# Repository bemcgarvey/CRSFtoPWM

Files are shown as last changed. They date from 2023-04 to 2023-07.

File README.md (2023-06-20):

# CRSFtoPWM  
  
A board to provide up to 10 PWM servo outputs using an inexpensive serial ELRS receiver.  Tested with a BetaFPV Nano 2400 Rx  
Includes a pressure sensor for baro altitude and vertical speed telemetery. 
  
### Features:  
* 8 PWM servo outputs with adjustable update rate from 50Hz to 333Hz
* 2 PWM outputs fixed at 50Hz
* All pwm outputs can be mapped to any channel
* Optional SBus output of all channels
* Altitude and VSpeed telemetry over ELRS/CRSF
* Rx battery telemetry over ELRS
* Vbat from 2S to 6S or optionally from servo rail
* Extra UART port can be configured for gps telemetry, debugging, or Betaflight passthrough for ELRS rx firmware updates
* Extra I2C port for future expansion?
* Windows client software for configuration over a USB-Serial (FTDI etc.) connection.

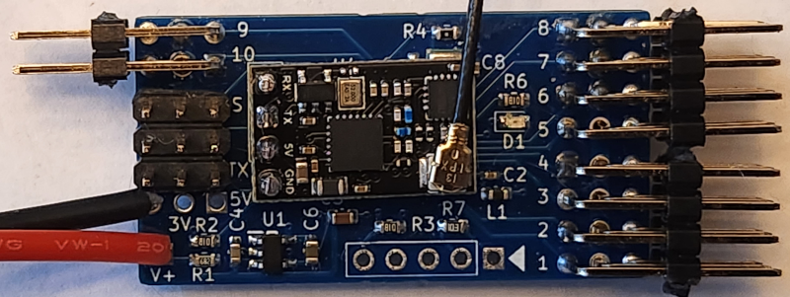
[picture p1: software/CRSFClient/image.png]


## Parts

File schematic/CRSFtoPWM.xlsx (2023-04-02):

Source: | C:\Projects\CRSFtoPWM\schematic\CRSFtoPWM.kicad_sch
Component Count: | 30
Ref | Qnty | Value | Footprint | Vendor
C1, C2, C8, C9, | 4 | 100nF | Capacitor_SMD:C_0402_1005Metric
C3, C6, | 2 | 10uF | Capacitor_SMD:C_0603_1608Metric
C4, | 1 | 1uF | Capacitor_SMD:C_0603_1608Metric
C5, | 1 | 1uF | Capacitor_SMD:C_0402_1005Metric
C7, | 1 | 2.2uF | Capacitor_SMD:C_0603_1608Metric
D1, | 1 | LED | LED_SMD:LED_0603_1608Metric
J1, | 1 | Bat+ | Connector_PinHeader_2.54mm:PinHeader_1x01_P2.54mm_Vertical
J2, | 1 | UART1/Rx | Connector_PinHeader_2.54mm:PinHeader_1x04_P2.54mm_Vertical
J3, | 1 | ICSP | Connector_PinHeader_2.54mm:PinHeader_1x05_P2.54mm_Vertical
J4, J5, J6, | 3 | TSW-104-08-G-T-RA | SamacSys_Parts:HDRRA12W64P254_3X4_1016X254X810P
J7, | 1 | TSW-102-08-L-T-RA | SamacSys_Parts:HDRRA6W64P254_3X2_508X254X810P
L1, | 1 | 470R | Inductor_SMD:L_0603_1608Metric
R1, | 1 | 6K8 | Resistor_SMD:R_0603_1608Metric
R2, R3, R6, | 3 | 1K | Resistor_SMD:R_0603_1608Metric
R4, R5, R7, | 3 | 10K | Resistor_SMD:R_0603_1608Metric
U1, | 1 | AP7375-50W5-7 | SamacSys_Parts:SOT95P285X140-5N
U2, | 1 | AP2210N-3.3TRG1 | SamacSys_Parts:SOT95P280X145-3N
U3, | 1 | ATSAMD21E18A-MU | SamacSys_Parts2:QFN50P500X500X100-33N-D
U4, | 1 | SN74AUP1G04DBVR | SamacSys_Parts2:SOT95P280X145-5N
U5, | 1 | MS563702BA03-50 | SamacSys_Parts2:MS5637_1

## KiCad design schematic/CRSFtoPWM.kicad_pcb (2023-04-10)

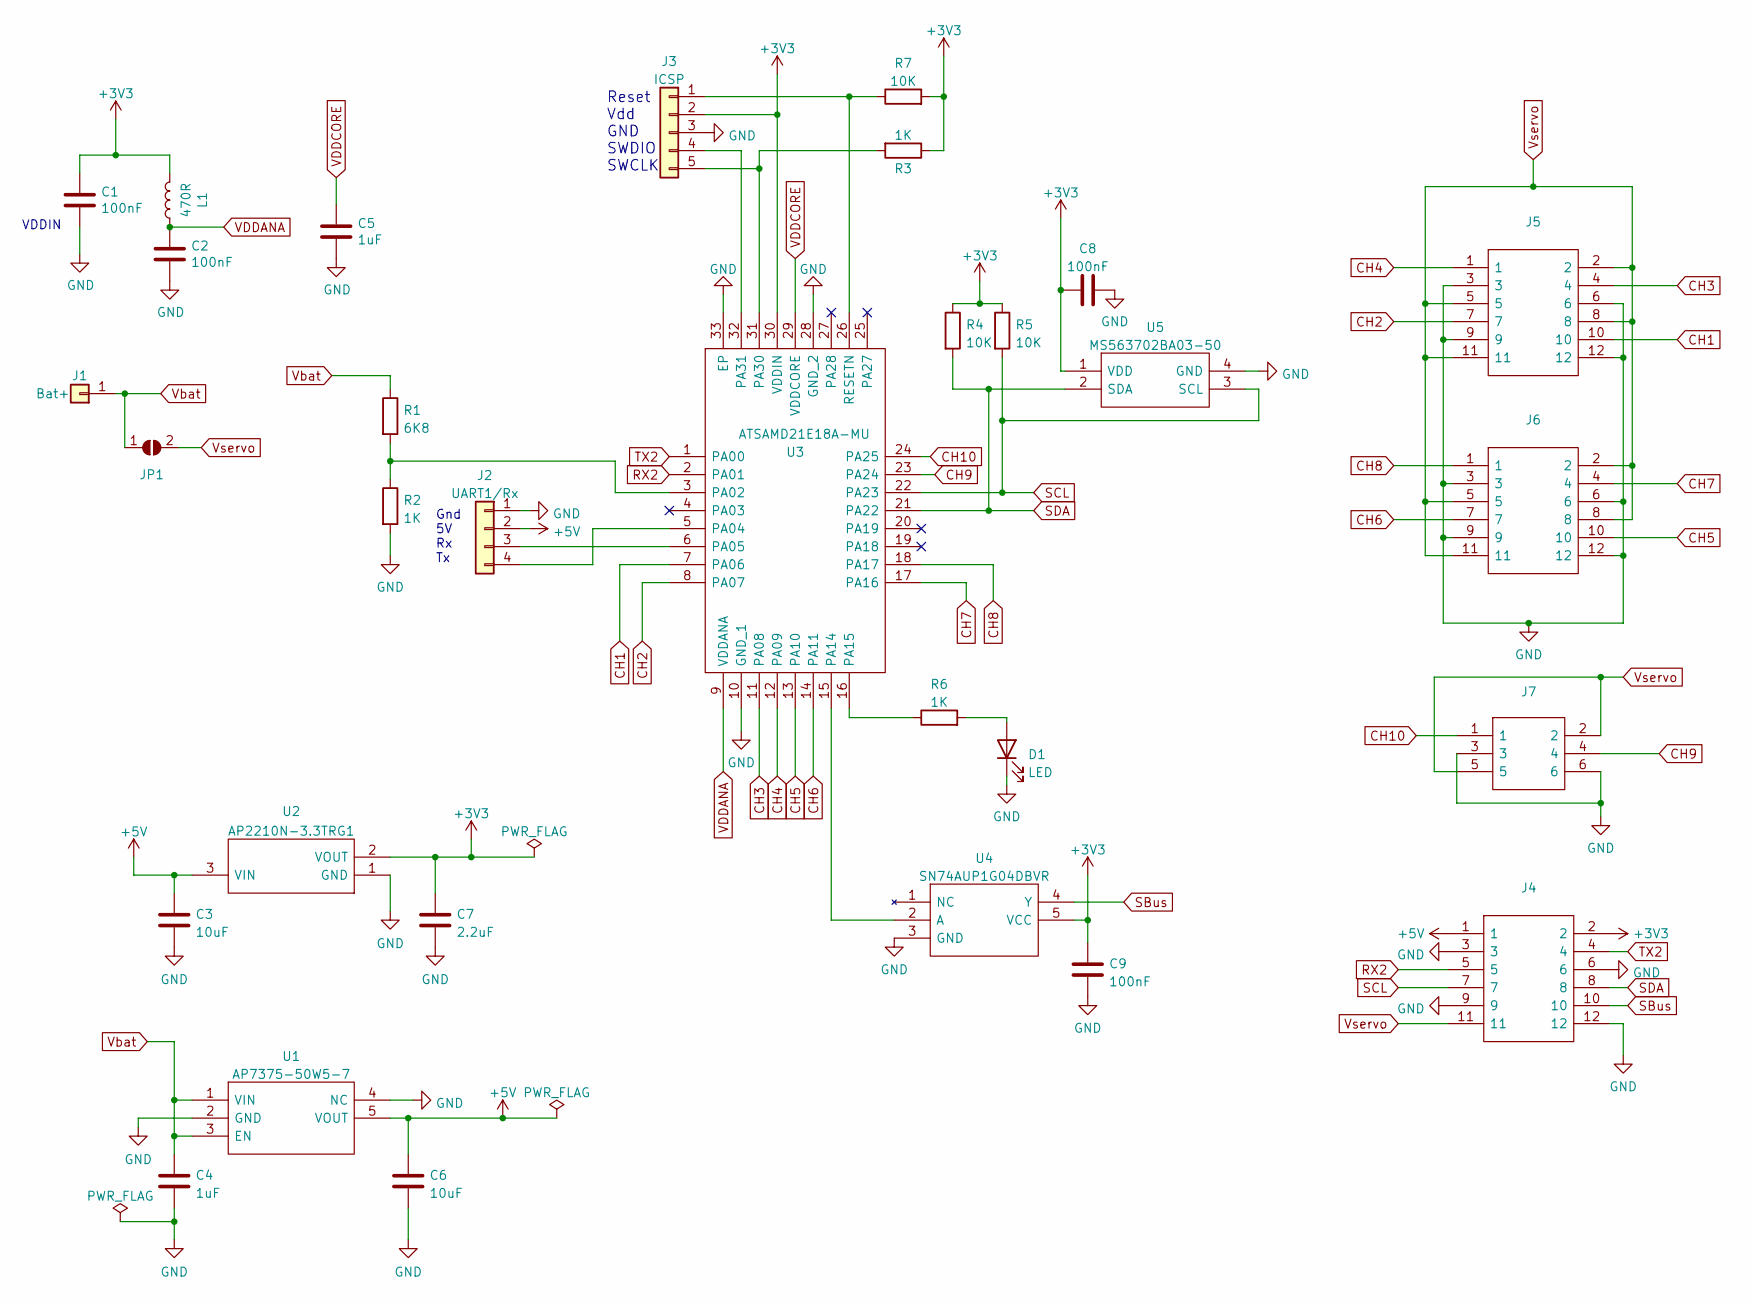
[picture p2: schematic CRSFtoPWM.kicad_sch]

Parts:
C1, C2, C8, C9: 100nF; C_0402_1005Metric
C3, C6: 10uF; C_0603_1608Metric
C4: 1uF; C_0603_1608Metric
C5: 1uF; C_0402_1005Metric
C7: 2.2uF; C_0603_1608Metric
D1: LED; LED_0603_1608Metric
J1: Bat+; PinHeader_1x01_P2.54mm_Vertical
J2: UART1/Rx; PinHeader_1x04_P2.54mm_Vertical
J3: ICSP; PinHeader_1x05_P2.54mm_Vertical
J4, J5, J6: TSW-104-08-G-T-RA; HDRRA12W64P254_3X4_1016X254X810P; Mouser Part Number 200-TSW10408GTRA
J7: TSW-102-08-L-T-RA; HDRRA6W64P254_3X2_508X254X810P; Mouser Part Number 200-TSW10208LTRA
JP1: SolderJumper_2_Open; SolderJumper-2_P1.3mm_Open_RoundedPad1.0x1.5mm
L1: 470R; L_0603_1608Metric
R1: 6K8; R_0603_1608Metric
R2, R3, R6: 1K; R_0603_1608Metric
R4, R5, R7: 10K; R_0603_1608Metric
U1: AP7375-50W5-7; SOT95P285X140-5N; Mouser Part Number 621-AP7375-50W5-7
U2: AP2210N-3.3TRG1; SOT95P280X145-3N; Mouser Part Number 621-AP2210N-3.3TRG1
U3: ATSAMD21E18A-MU; QFN50P500X500X100-33N-D; Mouser Part Number 556-ATSAMD21E18A-MU
U4: SN74AUP1G04DBVR; SOT95P280X145-5N; Mouser Part Number 595-SN74AUP1G04DBVR
U5: MS563702BA03-50; MS5637_1; Mouser Part Number 824-MS563702BA03-50

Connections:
+3V3: C1.1, C7.1, C8.1, C9.1, J3.2, J4.2, L1.2, R3.1, R4.1, R5.1, R7.2, U2.2 (VOUT), U3.30 (VDDIN), U4.5 (VCC), U5.1 (VDD)
+5V: C3.1, C6.1, J2.2, J4.1, U1.5 (VOUT), U2.3 (VIN)
CH1: J5.10, U3.7 (PA06)
CH2: J5.7, U3.8 (PA07)
CH3: J5.4, U3.11 (PA08)
CH4: J5.1, U3.12 (PA09)
CH5: J6.10, U3.13 (PA10)
CH6: J6.7, U3.14 (PA11)
CH7: J6.4, U3.17 (PA16)
CH8: J6.1, U3.18 (PA17)
CH9: J7.4, U3.23 (PA24)
CH10: J7.1, U3.24 (PA25)
GND: C1.2, C2.2, C3.2, C4.2, C5.2, C6.2, C7.2, C8.2, C9.2, D1.1 (K), J2.1, J3.3, J4.3, J4.6, J4.9, J4.12, J5.3, J5.6, J5.9, J5.12, J6.3, J6.6, J6.9, J6.12, J7.3, J7.6, R2.2, U1.2 (GND), U1.4 (NC), U2.1 (GND), U3.10 (GND_1), U3.28 (GND_2), U3.33 (EP), U4.3 (GND), U5.4 (GND)
unnamed: D1.2 (A), R6.2
unnamed: J2.3, U3.6 (PA05)
unnamed: J2.4, U3.5 (PA04)
unnamed: J3.1, R7.1, U3.26 (RESETN)
unnamed: J3.4, U3.32 (PA31)
unnamed: J3.5, R3.2, U3.31 (PA30)
unnamed: R1.2, R2.1, U3.3 (PA02)
unnamed: R6.1, U3.16 (PA15)
unnamed: U3.15 (PA14), U4.2 (A)
RX2: J4.5, U3.2 (PA01)
SBus: J4.10, U4.4 (Y)
SCL: J4.7, R5.2, U3.22 (PA23), U5.3 (SCL)
SDA: J4.8, R4.2, U3.21 (PA22), U5.2 (SDA)
TX2: J4.4, U3.1 (PA00)
VDDANA: C2.1, L1.1, U3.9 (VDDANA)
VDDCORE: C5.1, U3.29 (VDDCORE)
Vbat: C4.1, J1.1, JP1.1 (A), R1.1, U1.1 (VIN), U1.3 (EN)
Vservo: J4.11, J5.2, J5.5, J5.8, J5.11, J6.2, J6.5, J6.8, J6.11, J7.2, J7.5, JP1.2 (B)

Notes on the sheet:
Reset Vdd GND SWDIO SWCLK
Gnd 5V Rx Tx
VDDIN

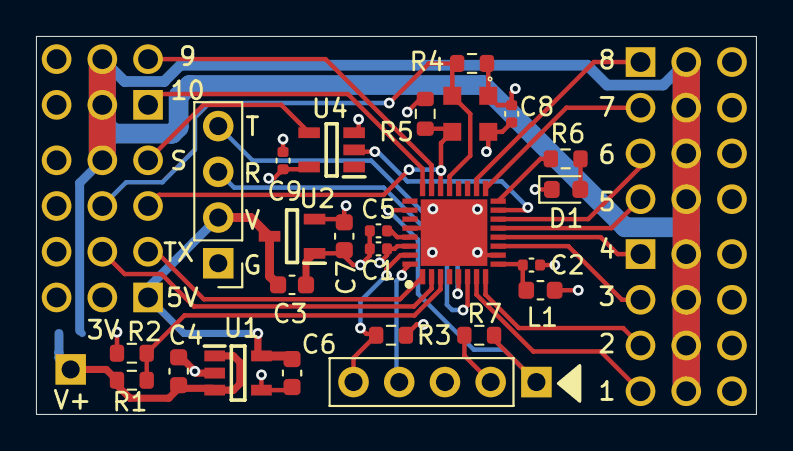
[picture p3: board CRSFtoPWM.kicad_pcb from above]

Board: 4 copper layers, 40.0 x 21.0 mm, 31 parts (1 on the bottom side), 31 nets.

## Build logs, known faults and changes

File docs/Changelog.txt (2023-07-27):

CRSFtoPWM change log

Firmware
	1.0 - Initial working version
	1.1 - Added UART passthrough option.
	1.2 - Added GPS telemetry
	1.3 - Fixed an rx error bug that prevented ELRS 3.3.0 from working.
	
Software
	1.0 - Initial version
	1.1 - Added GPS baud selection
	
Schematic/PCB
	1.0 - Initial version
	1.1 - 3.3V regulator now fed from 5.0V rail
		  Added solder pad to optionally connect servo rail to Vbat

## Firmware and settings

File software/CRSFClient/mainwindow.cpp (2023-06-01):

#include "mainwindow.h"
#include "ui_mainwindow.h"
#include <QtSerialPort/QSerialPortInfo>
#include "commands.h"
#include "settings.h"
#include <QMessageBox>
#include "aboutdialog.h"

MainWindow::MainWindow(QWidget *parent)
    : QMainWindow(parent), ui(new Ui::MainWindow), port(nullptr), state(STATE_IDLE) {
  ui->setupUi(this);
  portLabel = new QLabel();
  portLabel->setText("----");
  connectedLabel = new QLabel();
  connectedLabel->setText("Not Connected");
  ui->statusbar->addPermanentWidget(portLabel);
  ui->statusbar->addWidget(connectedLabel);
  connect(ui->menuPort, &QMenu::aboutToShow, this, &MainWindow::updatePortMenu);
}

MainWindow::~MainWindow() { delete ui; }

void MainWindow::updateControls()
{
    ui->out1ComboBox->setCurrentIndex(settings.ouputMap[0]);
    ui->out2ComboBox->setCurrentIndex(settings.ouputMap[1]);
    ui->out3ComboBox->setCurrentIndex(settings.ouputMap[2]);
    ui->out4ComboBox->setCurrentIndex(settings.ouputMap[3]);
    ui->out5ComboBox->setCurrentIndex(settings.ouputMap[4]);
    ui->out6ComboBox->setCurrentIndex(settings.ouputMap[5]);
    ui->out7ComboBox->setCurrentIndex(settings.ouputMap[6]);
    ui->out8ComboBox->setCurrentIndex(settings.ouputMap[7]);
    ui->out9ComboBox->setCurrentIndex(settings.ouputMap[8]);
    ui->out10ComboBox->setCurrentIndex(settings.ouputMap[9]);
    ui->throttleComboBox->setCurrentIndex(settings.throttleChannel);
    int index;
    index = ui->servoRateComboBox->findText(QString::number(settings.servoRate) + " Hz");
    ui->servoRateComboBox->setCurrentIndex(index);
    index = ui->sensorRateComboBox->findText(QString::number(settings.sensorRate) + " Hz");
    ui->sensorRateComboBox->setCurrentIndex(index);
    ui->failsafeComboBox->setCurrentIndex(settings.failsafeMode);
    ui->uartComboBox->setCurrentIndex(settings.uartMode);
    ui->sBusCheckBox->setChecked(settings.sBusEnabled);
    ui->voltageSpinBox->setValue(vBat);
    ui->gpsBaudComboBox->setCurrentIndex(settings.gpsBaud);
}

void MainWindow::updateSettings()
{
    settings.ouputMap[0] = ui->out1ComboBox->currentIndex();
    settings.ouputMap[1] = ui->out2ComboBox->currentIndex();
    settings.ouputMap[2] = ui->out3ComboBox->currentIndex();
    settings.ouputMap[3] = ui->out4ComboBox->currentIndex();
    settings.ouputMap[4] = ui->out5ComboBox->currentIndex();
    settings.ouputMap[5] = ui->out6ComboBox->currentIndex();
    settings.ouputMap[6] = ui->out7ComboBox->currentIndex();
    settings.ouputMap[7] = ui->out8ComboBox->currentIndex();
    settings.ouputMap[8] = ui->out9ComboBox->currentIndex();
    settings.ouputMap[9] = ui->out10ComboBox->currentIndex();
    settings.throttleChannel = ui->throttleComboBox->currentIndex();
    QString str;
    str = ui->servoRateComboBox->currentText();
    str.remove(" Hz");
    settings.servoRate = str.toShort();
    str = ui->sensorRateComboBox->currentText();
    str.remove(" Hz");
    settings.sensorRate = str.toShort();
    settings.failsafeMode = ui->failsafeComboBox->currentIndex();
    settings.uartMode = ui->uartComboBox->currentIndex();
    settings.sBusEnabled = ui->sBusCheckBox->isChecked() ? 1 : 0;
    settings.batCalibration = settings.batCalibration + (ui->voltageSpinBox->value() - vBat);
    settings.gpsBaud = ui->gpsBaudComboBox->currentIndex();
}

void MainWindow::updatePortMenu() {
  QList<QSerialPortInfo> portList = QSerialPortInfo::availablePorts();
  ui->menuPort->clear();
  for (auto &&i : portList) {
    QAction *action = ui->menuPort->addAction(i.portName(), this,
                                              &MainWindow::comPortSelected);
    action->setCheckable(true);
    if (i.portName() == portLabel->text()) {
      action->setChecked(true);
    }
  }
}

void MainWindow::comPortSelected()
{
    QAction *action = dynamic_cast<QAction *>(sender());
        if (port != nullptr) {
            port->close();
            delete port;
        }
        port = new QSerialPort(action->text(), this);
        if (port->open(QIODevice::ReadWrite)) {
            port->setBaudRate(QSerialPort::Baud115200);
            port->setDataBits(QSerialPort::Data8);
            port->setParity(QSerialPort::NoParity);
            port->setStopBits(QSerialPort::OneStop);
            portLabel->setText(action->text());
            connect(port, &QSerialPort::readyRead, this, &MainWindow::onReadyRead);
            ui->connectButton->setEnabled(true);
            buffer[0] = CMD_GET_VERSION;
            port->write(buffer, 1); //Send a command to prime serial port
        } else {
            delete port;
            port = nullptr;
            portLabel->setText("----");
            connectedLabel->setText("Not Connected");
            ui->connectButton->setEnabled(false);
        }
}

void MainWindow::onReadyRead() {
        int bytesReceived;
        switch (state) {
        case STATE_WAIT_VERSION:
            bytesReceived =
                static_cast<int>(port->read(&buffer[bufferPos], bytesNeeded));
            bytesNeeded -= bytesReceived;
            bufferPos += bytesReceived;
            if (bytesNeeded == 0) {
                if (*(uint32_t *)buffer == DEVICE_SIGNATURE) {
                    connectedLabel->setText(QString("Firmware Version %1.%2")
                                                .arg((int)buffer[5])
                                                .arg((int)buffer[4]));
                    ui->connectButton->setEnabled(false);
                    ui->readSettingsButton->setEnabled(true);
                    ui->saveSettingsButton->setEnabled(true);
                    on_readSettingsButton_clicked();
                } else {
                    state = STATE_IDLE;
                    QMessageBox::critical(this, "CRSF", "Unable to connect");
                }
            }
            break;
        case STATE_WAIT_SETTINGS:
        case STATE_WAIT_VERIFY:
            bytesReceived =
                static_cast<int>(port->read(&buffer[bufferPos], bytesNeeded));
            bytesNeeded -= bytesReceived;
            bufferPos += bytesReceived;
            if (bytesNeeded == 0) {
                if (state == STATE_WAIT_SETTINGS) {
                    memcpy(&settings, buffer, sizeof(Settings));
                    vBat = *(float *)&buffer[sizeof(Settings)];
                    ui->statusbar->showMessage("Settings read", 2000);
                    updateControls();
                    state = STATE_IDLE;
                } else if (state == STATE_WAIT_VERIFY) {
                    if (memcmp(buffer, &settings, sizeof(settings)) != 0) {
                        QMessageBox::critical(this, "CRSF", "Verify settings failed.  Settings are not saved.");
                    } else {
                        QMessageBox::information(this, "CRSF", "Settings saved.");
                    }
                    state = STATE_IDLE;
                }
            }
            break;
        case STATE_IDLE:
            port->read(buffer, 64); //We're idle so discard any received bytes
            break;
        }
}

void MainWindow::on_connectButton_clicked() {
        buffer[0] = CMD_GET_VERSION;
        bytesNeeded = 6;
        bufferPos = 0;
        state = STATE_WAIT_VERSION;
        port->write(buffer, 1);
}

void MainWindow::on_readSettingsButton_clicked()
{
    buffer[0] = CMD_GET_SETTINGS;
    bytesNeeded = sizeof(Settings) + sizeof(float);
    bufferPos = 0;
    state = STATE_WAIT_SETTINGS;
    port->write(buffer, 1);
}


void MainWindow::on_saveSettingsButton_clicked()
{
    updateSettings();
    buffer[0] = CMD_SAVE_SETTINGS;
    port->write(buffer, 1);
    memcpy(buffer, &settings, sizeof(Settings));
    port->write(buffer, sizeof(Settings));
    bytesNeeded = sizeof(Settings);
    bufferPos = 0;
    state = STATE_WAIT_VERIFY;
}


void MainWindow::on_actionExit_triggered()
{
    close();
}


void MainWindow::on_actionAbout_triggered()
{
    auto dlg = std::make_unique<AboutDialog>(this);
    dlg->exec();
}


void MainWindow::on_uartComboBox_currentIndexChanged(int index)
{
    if (index == 1) {
        ui->gpsBaudComboBox->setEnabled(true);
    } else {
        ui->gpsBaudComboBox->setEnabled(false);
    }
}

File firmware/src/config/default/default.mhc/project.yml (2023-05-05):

files:
- generatedChecksum: E4894B6355AF41AED546E4C6C20005C1
  logicalPath: FreeRTOS/Source
  name: FreeRTOS_tasks.c
  physicalPath: ../../third_party/rtos/FreeRTOS/Source
  security: NON_SECURE
  type: SOURCE
  userChecksum: E4894B6355AF41AED546E4C6C20005C1
- generatedChecksum: 4490B523D4D89767AF3FE31B825F7F6D
  logicalPath: FreeRTOS/Source
  name: croutine.c
  physicalPath: ../../third_party/rtos/FreeRTOS/Source
  security: NON_SECURE
  type: SOURCE
  userChecksum: 4490B523D4D89767AF3FE31B825F7F6D
- generatedChecksum: 0E0E8AECB67046FEA847B359ACE7A1F6
  logicalPath: FreeRTOS/Source
  name: event_groups.c
  physicalPath: ../../third_party/rtos/FreeRTOS/Source
  security: NON_SECURE
  type: SOURCE
  userChecksum: 0E0E8AECB67046FEA847B359ACE7A1F6
- generatedChecksum: E45D1648EFC10229D7BE94DB19221FF7
  logicalPath: config/default
  name: exceptions.c
  physicalPath: ''
  security: NON_SECURE
  type: SOURCE
  userChecksum: E45D1648EFC10229D7BE94DB19221FF7
- generatedChecksum: CF89BE92AE72229779903C2E9A760455
  logicalPath: config/default
  name: freertos_hooks.c
  physicalPath: ''
  security: NON_SECURE
  type: SOURCE
  userChecksum: CF89BE92AE72229779903C2E9A760455
- generatedChecksum: 31CEE4650E24C72160696DF93B55B48D
  logicalPath: FreeRTOS/Source/portable/MemMang
  name: heap_1.c
  physicalPath: ../../third_party/rtos/FreeRTOS/Source/portable/MemMang
  security: NON_SECURE
  type: SOURCE
  userChecksum: 31CEE4650E24C72160696DF93B55B48D
- generatedChecksum: 087C96A263E386CB321A5719FA71F0B9
  logicalPath: config/default
  name: initialization.c
  physicalPath: ''
  security: NON_SECURE
  type: SOURCE
  userChecksum: 087C96A263E386CB321A5719FA71F0B9
- generatedChecksum: 370091B8E3F6A11CE069C291398138DA
  logicalPath: config/default
  name: interrupts.c
  physicalPath: ''
  security: NON_SECURE
  type: SOURCE
  userChecksum: 370091B8E3F6A11CE069C291398138DA
- generatedChecksum: 2CDCA8CDF135BDEB85FDFC0A2A991C0B
  logicalPath: config/default
  name: libc_syscalls.c
  physicalPath: ''
  security: NON_SECURE
  type: SOURCE
  userChecksum: 2CDCA8CDF135BDEB85FDFC0A2A991C0B
- generatedChecksum: 47F98BAFD5D2A077AB529D10DB870AFF
  logicalPath: FreeRTOS/Source
  name: list.c
  physicalPath: ../../third_party/rtos/FreeRTOS/Source
  security: NON_SECURE
  type: SOURCE
  userChecksum: 47F98BAFD5D2A077AB529D10DB870AFF
- generatedChecksum: null
  logicalPath: ''
  name: main.c
  physicalPath: ../..
  security: NON_SECURE
  type: SOURCE
  userChecksum: null
- generatedChecksum: 8FDD6248506F28B32C4F5FD9AA0D9C6F
  logicalPath: config/default/osal
  name: osal_freertos.c
  physicalPath: osal
  security: NON_SECURE
  type: SOURCE
  userChecksum: 8FDD6248506F28B32C4F5FD9AA0D9C6F
- generatedChecksum: B8BC9F076A3ABE2B20981EF2F7CA9CDE
  logicalPath: config/default/peripheral/adc
  name: plib_adc.c
  physicalPath: peripheral/adc
  security: NON_SECURE
  type: SOURCE
  userChecksum: B8BC9F076A3ABE2B20981EF2F7CA9CDE
- generatedChecksum: 28A40DBE1196D5F7D07C5A474F454767
  logicalPath: config/default/peripheral/clock
  name: plib_clock.c
  physicalPath: peripheral/clock
  security: NON_SECURE
  type: SOURCE
  userChecksum: 28A40DBE1196D5F7D07C5A474F454767
- generatedChecksum: 75DF079CB794845D267E8908F113646B
  logicalPath: config/default/peripheral/dmac
  name: plib_dmac.c
  physicalPath: peripheral/dmac
  security: NON_SECURE
  type: SOURCE
  userChecksum: 75DF079CB794845D267E8908F113646B
- generatedChecksum: C3ECDED3D6301DB0DE622293ED615D21
  logicalPath: config/default/peripheral/evsys
  name: plib_evsys.c
  physicalPath: peripheral/evsys
  security: NON_SECURE
  type: SOURCE
  userChecksum: C3ECDED3D6301DB0DE622293ED615D21
- generatedChecksum: 6EE4152F74183898D211482C1176074F
  logicalPath: config/default/peripheral/nvic
  name: plib_nvic.c
  physicalPath: peripheral/nvic
  security: NON_SECURE
  type: SOURCE
  userChecksum: 6EE4152F74183898D211482C1176074F
- generatedChecksum: CDBE0E5D94C53410F5F34B566B5FF51F
  logicalPath: config/default/peripheral/nvmctrl
  name: plib_nvmctrl.c
  physicalPath: peripheral/nvmctrl
  security: NON_SECURE
  type: SOURCE
  userChecksum: CDBE0E5D94C53410F5F34B566B5FF51F
- generatedChecksum: 40BE387D1DAD9A04BF4E79D9BB271213
  logicalPath: config/default/peripheral/pm
  name: plib_pm.c
  physicalPath: peripheral/pm
  security: NON_SECURE
  type: SOURCE
  userChecksum: 40BE387D1DAD9A04BF4E79D9BB271213
- generatedChecksum: A8A6AC3E0417DCBA2BD9762D256FC51C
  logicalPath: config/default/peripheral/port
  name: plib_port.c
  physicalPath: peripheral/port
  security: NON_SECURE
  type: SOURCE
  userChecksum: A8A6AC3E0417DCBA2BD9762D256FC51C
- generatedChecksum: B8AD9BC3F3812FB92FFE2D8D7E61946C
  logicalPath: config/default/peripheral/sercom/usart
  name: plib_sercom0_usart.c
  physicalPath: peripheral/sercom/usart
  security: NON_SECURE
  type: SOURCE
  userChecksum: B8AD9BC3F3812FB92FFE2D8D7E61946C
- generatedChecksum: 79E4AABE0A96AFBA9500DF6C743E84FB
  logicalPath: config/default/peripheral/sercom/usart
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

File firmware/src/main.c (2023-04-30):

/////////////////////////////////////////////////////
// Project: CRSFtoPWM                              //
// File: main.c                                    //
// Target: ATSAMD21E18A                            // 
// Compiler: XC32                                  //
// Author: Brad McGarvey                           //
// License: GNU General Public License v3.0        //
// Description: main function                      //
/////////////////////////////////////////////////////

#include <stddef.h>                     // Defines NULL
#include <stdbool.h>                    // Defines true
#include <stdlib.h>                     // Defines EXIT_FAILURE
#include "definitions.h"                // SYS function prototypes
#include "tasks.h"
#include "settings.h"
#include "serial.h"

int main(void) {
    /* Initialize all modules */
    wdtResetHappened = false;
    if (PM_ResetCauseGet() == PM_RESET_CAUSE_WDT_RESET) {
        wdtResetHappened = true;
    }
    bool serialDetected = false;
    if (!wdtResetHappened) {
        serialDetected = detectSerial();
    }
    SYS_Initialize(NULL);
    if (wdtResetHappened) {
        if (settings.uartMode == UART_DEBUG) {
            printf("Watchdog timeout!!\r\n");
        }
    }
    if (settings.uartMode == UART_DEBUG) {
        printf("Starting\r\n");
    }
    loadSettings();
    if (settings.uartMode == UART_DEBUG) {
        printf("Settings loaded\r\n");
        printf("Servo rate %d Hz, Sensor rate %d Hz\r\n", settings.servoRate, settings.sensorRate);
    }
    if (serialDetected) {
        if (settings.uartMode == UART_DEBUG) {
            printf("Serial detected\r\n");
        }
        serialMain(); //Does not return;
    }
    initTasks(); //Starts scheduler, does not return
    while (true) {

    }
    return ( EXIT_FAILURE);
}

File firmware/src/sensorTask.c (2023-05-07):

/////////////////////////////////////////////////////
// Project: CRSFtoPWM                              //
// File: sensorTask.c                              //
// Target: ATSAMD21E18A                            // 
// Compiler: XC32                                  //
// Author: Brad McGarvey                           //
// License: GNU General Public License v3.0        //
// Description: sensor task handler                //
/////////////////////////////////////////////////////

#include "definitions.h"
#include "sensorTask.h"
#include "sensors.h"
#include "settings.h"
#include "debug.h"
#include "crsf.h"
#include "rtosHandles.h"

TaskHandle_t sensorTaskHandle;
#define INITIAL_ALT_SAMPLES     4

void sensorTask(void *pvParameter) {
    int delay;
    float dAlt = 0;
    float groundLevel = 0;
    float lastAltitude = 0;
    int initSamples = INITIAL_ALT_SAMPLES;
    int samplePeriod;
    CRSF_sensor_gps gps;
    
    vTaskDelay(500);
    initSensors();
    if (settings.uartMode == UART_GPS) {
        delay = 333 / settings.sensorRate;
    } else {
        delay = 500 / settings.sensorRate;
    }
    debugMsg("Sensors initialized");
    if (altimeterHealthy) {
        debugMsg("Altimeter good");
    } else {
        debugMsg("Altimeter failed");
    }
    while (1) {
        if (altimeterHealthy) {
            vTaskDelay(delay - PRESSURE_SAMPLE_MS);
            float alt = getAltitude();
            if (initSamples > 0) {
                --initSamples;
                groundLevel += alt;
                if (initSamples == 0) {
                    groundLevel /= INITIAL_ALT_SAMPLES;
                    samplePeriod = settings.sensorRate;
                    lastAltitude = 0;
                }
            }
            if (initSamples == 0) {
                alt = alt - groundLevel;
                --samplePeriod;
                if (samplePeriod == 0) {
                    dAlt = alt - lastAltitude;
                    lastAltitude = alt;
                    samplePeriod = settings.sensorRate;
                }
            }
            sendAltitudeTelem(alt, dAlt);
        } else {
            vTaskDelay(delay);
        }
        vTaskDelay(delay);
        float v = getVBat();
        sendBatteryTelem(v);
        if (settings.uartMode == UART_GPS) {
            vTaskDelay(delay);
            if (xQueueReceive(gpsPacketQueueHandle, &gps, 0) == pdTRUE) {
                sendGPSTelem(&gps);
            }
        }
        xTaskNotify(watchdogTaskHandle, SENSOR_TASK_NOTIFY, eSetBits);
    }
}

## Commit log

2023-01-26 Initial KiCad project
    [CRSFtoPWM.kicad_pcb, CRSFtoPWM.kicad_sch]
2023-01-31 Draft schematic
    [CRSFtoPWM.kicad_sch]
2023-01-31 Pin updates
2023-01-31 Changed ICSP pullups
    per datasheet
    [CRSFtoPWM.kicad_sch]
2023-01-31 Added two more outputs
    [CRSFtoPWM.kicad_sch]
2023-01-31 Footprints assigned
    [CRSFtoPWM.kicad_sch]
2023-01-31 Updated some footprints
    [CRSFtoPWM.kicad_sch]
2023-02-01 Changed connections to improve pcb layout
    [CRSFtoPWM.kicad_sch]
2023-02-01 Initial pcb parts layout
    Also fixed VDDANA
    Made some schematic changes to improve layout
    [CRSFtoPWM.kicad_pcb, CRSFtoPWM.kicad_sch]
2023-02-01 Pcb fully routed - needs optimization
    [CRSFtoPWM.kicad_pcb, CRSFtoPWM.kicad_sch]
2023-02-02 Smaller pcb and tweaks
    [CRSFtoPWM.kicad_pcb, CRSFtoPWM.kicad_sch]
2023-02-03 Added text, minor tweaks
    [CRSFtoPWM.kicad_pcb, CRSFtoPWM.kicad_sch]
2023-02-04 Improved Vservo current capacity
    [CRSFtoPWM.kicad_pcb, CRSFtoPWM.kicad_sch]
2023-02-04 Improved Rx,Tx traces
    [CRSFtoPWM.kicad_pcb]
2023-02-04 Improved SCL,SDA traces
    [CRSFtoPWM.kicad_pcb]
2023-02-04 Added pullup to RESET
    Updated pins in Harmony
    [CRSFtoPWM.kicad_pcb, CRSFtoPWM.kicad_sch]
2023-02-05 Fixed JLC text
    [CRSFtoPWM.kicad_pcb]
2023-02-07 Fixed fill zones
    [CRSFtoPWM.kicad_pcb]
2023-03-13 Generated gerbers
    [CRSFtoPWM-B_Cu.gbl, CRSFtoPWM-B_Mask.gbs, CRSFtoPWM-B_Silkscreen.gbo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]
2023-04-01 Generated BOM
    [CRSFtoPWM.xlsx]
2023-04-02 Made labels consistent
    [CRSFtoPWM.kicad_sch]
2023-04-02 Updated BOM
    [CRSFtoPWM.xlsx]
2023-04-04 Tested pressure sensor
2023-04-07 Updated schematic to correct channel numbering
    [CRSFtoPWM.kicad_pcb, CRSFtoPWM.kicad_sch]
2023-04-08 DMA working
2023-04-08 Improved DMA handling
2023-04-10 Changed power circuit
    3.3V regulator now uses regulated 5V for input. Less load on 3.3V regulator and only the 5V regulator has high voltage input.
    [CRSFtoPWM.kicad_pcb, CRSFtoPWM.kicad_sch]
2023-04-10 Changed input cap back to 0603 and new gerbers
    [CRSFtoPWM-B_Cu.gbl, CRSFtoPWM-B_Mask.gbs, CRSFtoPWM-B_Silkscreen.gbo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]
2023-04-10 Added jumper to allow power from VServo
    [CRSFtoPWM-B_Cu.gbl, CRSFtoPWM-B_Mask.gbs, CRSFtoPWM-B_Silkscreen.gbo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]
2023-04-11 Improved debugMsg
    Now uses printf format
2023-04-12 Voltage calibration working
2023-04-15 Improved pressure calculations
2023-04-28 Simplified pressure calculations
2023-04-30 Removed reboot - software does it
    [crsf_uart.c, tasks.c]
2023-05-10 Changed comments to V 1.1
    [CRSFtoPWM.kicad_sch]
2023-05-11 Set default uart mode to passthrough
2023-07-27 Fixed uart error handler bug
    [crsf_uart.c, usart.c]
